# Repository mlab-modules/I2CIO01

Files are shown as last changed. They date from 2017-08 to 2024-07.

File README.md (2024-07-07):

# I2CIO01A - I2C IO Expander

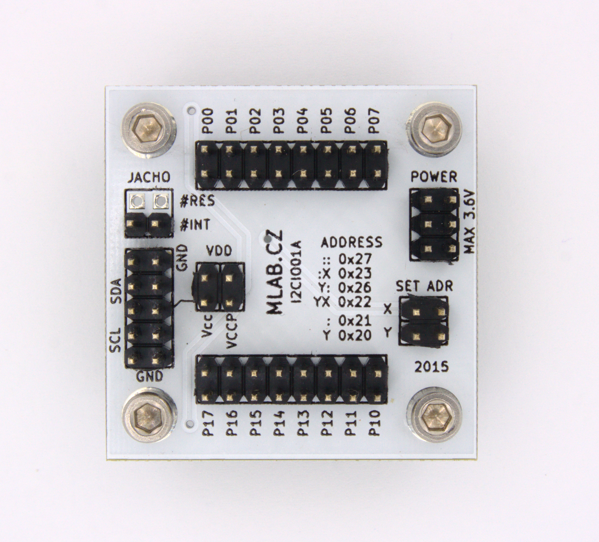
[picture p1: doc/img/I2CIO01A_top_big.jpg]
I2CIO01A


## Overview

The I2CIO01 module is a GPIO expander designed for operation in the range of 1.65 to 5.5 V. It provides general-purpose remote I/O expansion via the I²C interface. The module comprises two 8-bit Configurable, Input Ports, Output Port, and Polarity Inversion registers.

## Features

- **Operating Voltage:** 1.65 to 5.5 V
- **Interfaces:** I²C, up to 400 kHz
- **GPIO Ports:** 16-bit expansion using either TCA6416A or TCA9535 IC
- **Address Selection:**
  - TCA6416A: 2 I2C addresses, includes a reset pin
  - TCA9535: 4 I2C addresses
- **Interrupt Capabilities:** Both ICs support interrupt output
- **Package Dimensions:** 40.13 x 40.13 x 16 mm

## Technical Specifications

| Parameter | Value | Note |
|---|---|---|
| Power Supply | Max. 3.6 V | |
| ICs Used | TCA6416A or TCA9535 | |
| Interface bus | I²C | Frequency up to 400 kHz |
| Main Usage | I²C IO expander | |
| Dimensions | 40.13 x 40.13 x 16 mm | Height above the baseboard |

## Design Details

### IC Selection variants
- **TCA6416A:**
  - Populate RES, do not populate ADR X
  - Jumper to Vccp and VDD
- **TCA9535:**
  - Do not populate RES, populate ADR X
  - Jumper to Vccp and VDD

### Schematic and Layout

The module's design and layout files can be found in the `hw/sch_pcb` directory. The board is designed using KiCad.

## Bill of Materials

| Designator | Type | Package | Quantity |
|---|---|---|---|
| J3 | JUMP_3X2 | Pin_Header_Straight_2x03 | 1 |
| R1, R2, R3, ... | 10k | SMD-0805 | 13 |
| U1 | TCA6416A | TSSOP-28 | 1 |
| J8, J5 | CONN1_2 | Pin_Header_Straight_1x02 | 2 |
| P1, P2, P3, P4  | MountingHole_3mm | | 4 |
| J1 | JUMP_2X2 | Pin_Header_Straight_2x02 | 1 |
| J2 | JUMP_5X2 | Pin_Header_Straight_2x05 | 1 |
| J6, J7 | JUMP_8X2 | Pin_Header_Straight_2x08 | 2 |
| J4, J9 | CONN_2 | Pin_Header_Straight_1x02 | 2 |
| C1 | 10uF | SMD-0805 | 1 |
| C2 | 100nF | SMD-0805 | 1 |
| D1 | BZV55C-3,6V | Diode-MiniMELF_Standard | 1 |

## Assembly and Testing

1. **Assembly:** Follow the provided schematic and BOM for assembling the module.
2. **Initial Inspection:** Perform a visual inspection to ensure no shorts on the power supply.
3. **Testing:** No additional setup is required beyond the initial inspection.

For more detailed information on each component, please refer to their respective datasheets:

- [TCA6416A Datasheet](https://www.ti.com/product/TCA6416A)
- [TCA9535 Datasheet](https://www.ti.com/product/TCA9535)

## Contributing

Contributions are welcome! Please fork this repository and submit a pull request with your changes.

## Contact

For more information, visit the [MLAB website](http://www.mlab.cz) or contact us at support@mlab.cz.

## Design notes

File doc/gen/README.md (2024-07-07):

# PCB

Board size: 40.13x40.13 mm (1.58x1.58 inches)

- This is the size of the rectangle that contains the board
- Thickness: 1.6 mm (63 mils)
- Material: FR4
- Finish: HAL
- Layers: 2
- Copper thickness: 35 µm

Solder mask: TOP / BOTTOM

- Color: Green

Silk screen: TOP / BOTTOM

- Color: White

# Important sizes

Clearance: 0.2 mm (8 mils)

Track width: 0.38 mm (15 mils)

- By design rules: 0.25 mm (10 mils)

Drill: 0.75 mm (30 mils)

- Vias: 0.75 mm (30 mils) [Design: 0.6 mm (24 mils)]
- Pads: 1.0 mm (39 mils)
- The above values are real drill sizes, they add 0.1 mm (4 mils) to plated holes (PTH)

Via: 0.89/0.64 mm (35/25 mils)

- By design rules: 0.89/0.51 mm (35/20 mils)
- Micro via: yes [0.51/0.13 mm (20/5 mils)]
- Buried/blind via: yes
- Total: 3 (thru: 3 buried/blind: 0 micro: 0)

Outer Annular Ring: 0.07 mm (3 mils)

- By design rules: 0.33 mm (13 mils)

Eurocircuits class: 10A
- Using min drill 0.75 mm for an OAR of 0.07 mm

# General stats

Components count: (SMD/THT)

- Top: 0/13 (THT)
- Bottom: 25/0 (SMD)

Defined tracks:

- 0.38 mm (15 mils)
- 0.51 mm (20 mils)

Used tracks:

- 0.38 mm (15 mils) (161) defined: yes
- 0.51 mm (20 mils) (52) defined: yes

Defined vias:

Used vias:

- 0.89/0.64 mm (35/25 mils) (Count: 3, Aspect: 1.8 A) defined: no

Holes (excluding vias):

- 0.9 mm (35 mils) (60)
- 3.0 mm (118 mils) (4)

Oval holes:

Drill tools (including vias and computing adjusts and rounding):

- 0.75 mm (30 mils) (3)
- 1.0 mm (39 mils) (60)
- 3.1 mm (122 mils) (4)

Solder paste stats:

Using a paste with 87.75 % alloy, that has an specific gravity for the alloy of 7.4 g/cm³
and 1.0 g/cm³ for the flux. This paste has an specific gravity of  4.15 g/cm³.

The stencil thickness is  0.12 mm.

| Side | Pads with paste | Area [mm²] | Paste [g] |
|---|---|---|---|
| Total  | 72 | 76.34 | 0.38 |

Note: this is just an approximation to the theoretical value. Margins of the solder mask and waste aren't computed.

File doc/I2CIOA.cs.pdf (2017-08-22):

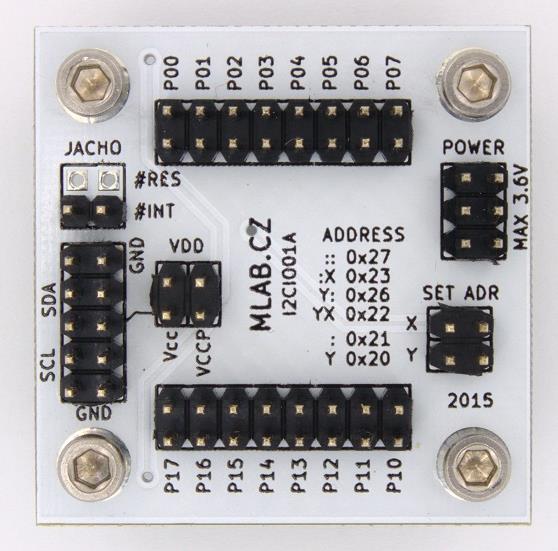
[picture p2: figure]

I2CIO01A / 2016-02-26 / jacho/ http://www.mlab.cz | 1 / 4
I2CIO01A | MLAB

# 16-Bit I2C expander

Jan Chroust

### Modul může být osazen integrovaným obvodem TCA6416A nebo

TCA9535. Oba obvody umožňují vytvořit 16-Bitový I2C expander. Obvod TCA9535 nabízí možnost volby mezi čtveřicí I2C adres,

### kdežto TCA6416A nabízí pouze dvě. TCA6416A má navíc resetový

pin. Oba dva obvody umožňují interrupt.

# 1. Technické parametry

Parametr | Hodnota | Poznámka
Napájení | Max. 3,6 V
Integrovaný obvod | TCA6416A nebo TCA9535
Rozhraní | I2C | Frekvence až 400kHz
Hlavní využití | I2C expander
Rozměry | 40.13 x 40.13 x 16 mm | Výška nad základní deskou

I2CIO01A | MLAB

# 2. Popis konstrukce

## 2.1. Úvod

TCA6416A – osadit RES a neosadit ADR X + jump na Vccp a VDD

TCA9535 - neosadit RES a osadit ADR X + jump na Vccp a VDD

I2CIO01A | MLAB

## 2.2. Zapojení

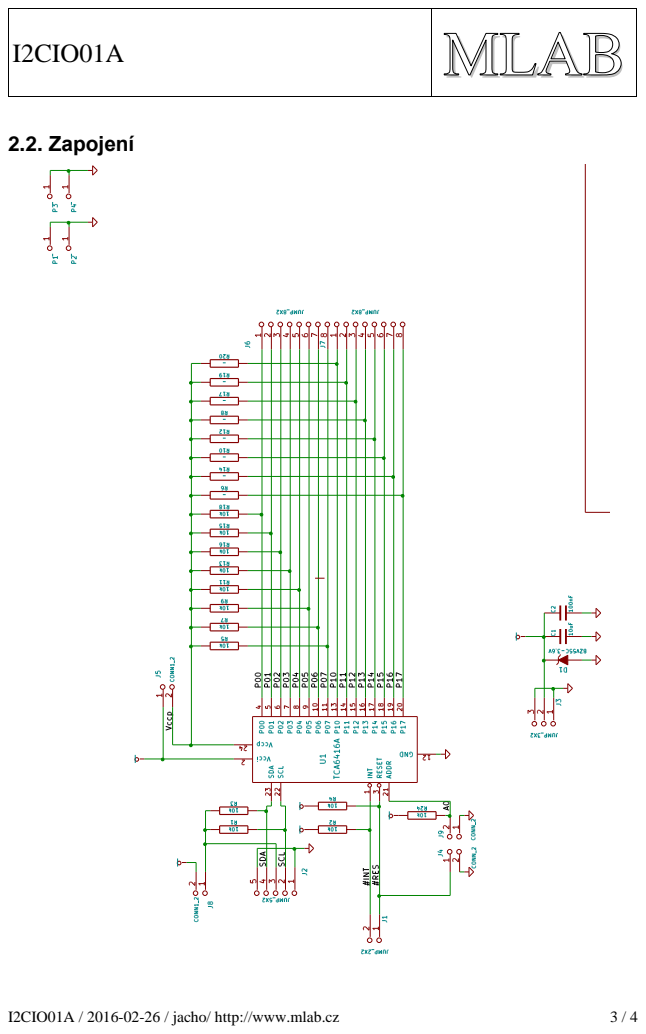
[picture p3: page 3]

I2CIO01A | MLAB

# 3. Osazení a oživení

## 3.1. Osazení

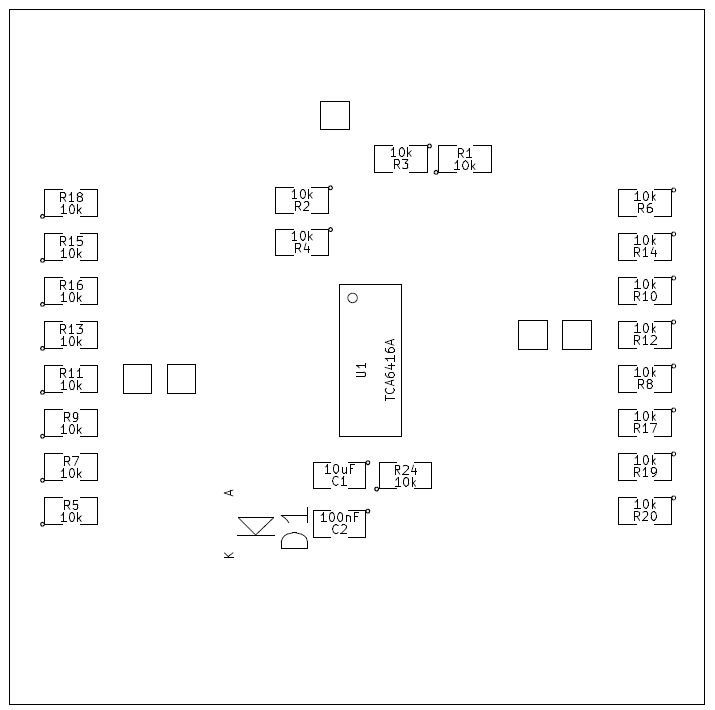
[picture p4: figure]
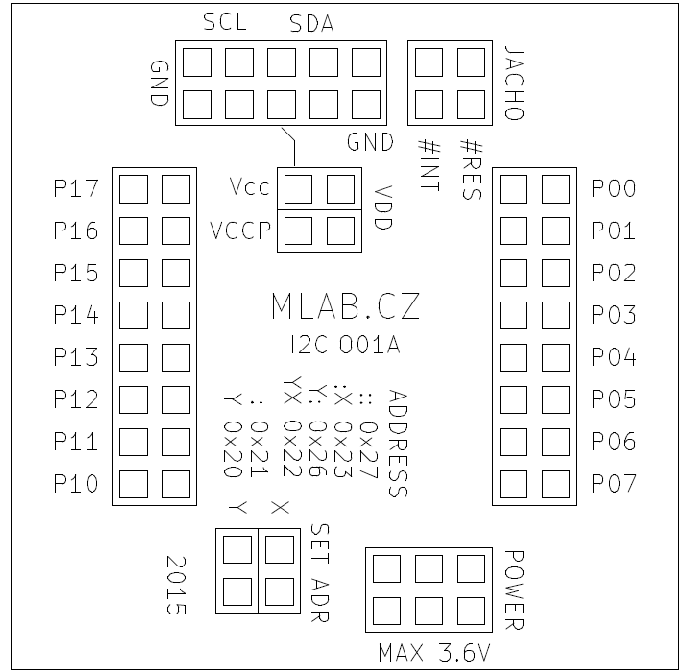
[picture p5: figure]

Označení | Typ | Pouzdro | Počet
J3 | JUMP_3X2 | Pin_Header_Straight_2x03 | 1
R1,R2,R3,R4,R5,R7,R 9,R11,R13,R15,R16,R1 8,R24 | 10k | SMD-0805 | 13
R6,R8,R10,R12,R14,R 17,R19,R20 | - | SMD-0805 | 8
U1 | TCA6416A | TSSOP-28 | 1
J8,J5 | CONN1_2 | Pin_Header_Straight_1x02 | 2
P1,P2,P3,P4 | _ | MountingHole_3mm | 4
J1 | JUMP_2X2 | Pin_Header_Straight_2x02 | 1
J2 | JUMP_5X2 | Pin_Header_Straight_2x05 | 1
J6,J7 | JUMP_8X2 | Pin_Header_Straight_2x08 | 2
J4,J9 | CONN_2 | Pin_Header_Straight_1x02 | 2
C1 | 10uF | SMD-0805 | 1
C2 | 100nF | SMD-0805 | 1
D1 | BZV55C-3,6V | Diode-MiniMELF_Standard | 1

## 3.2. Oživení

Po osazení modulu je dobré provést vizuální kontrolu, případně proměřit, zda na napájení není zkrat. Další oživení není potřeba.

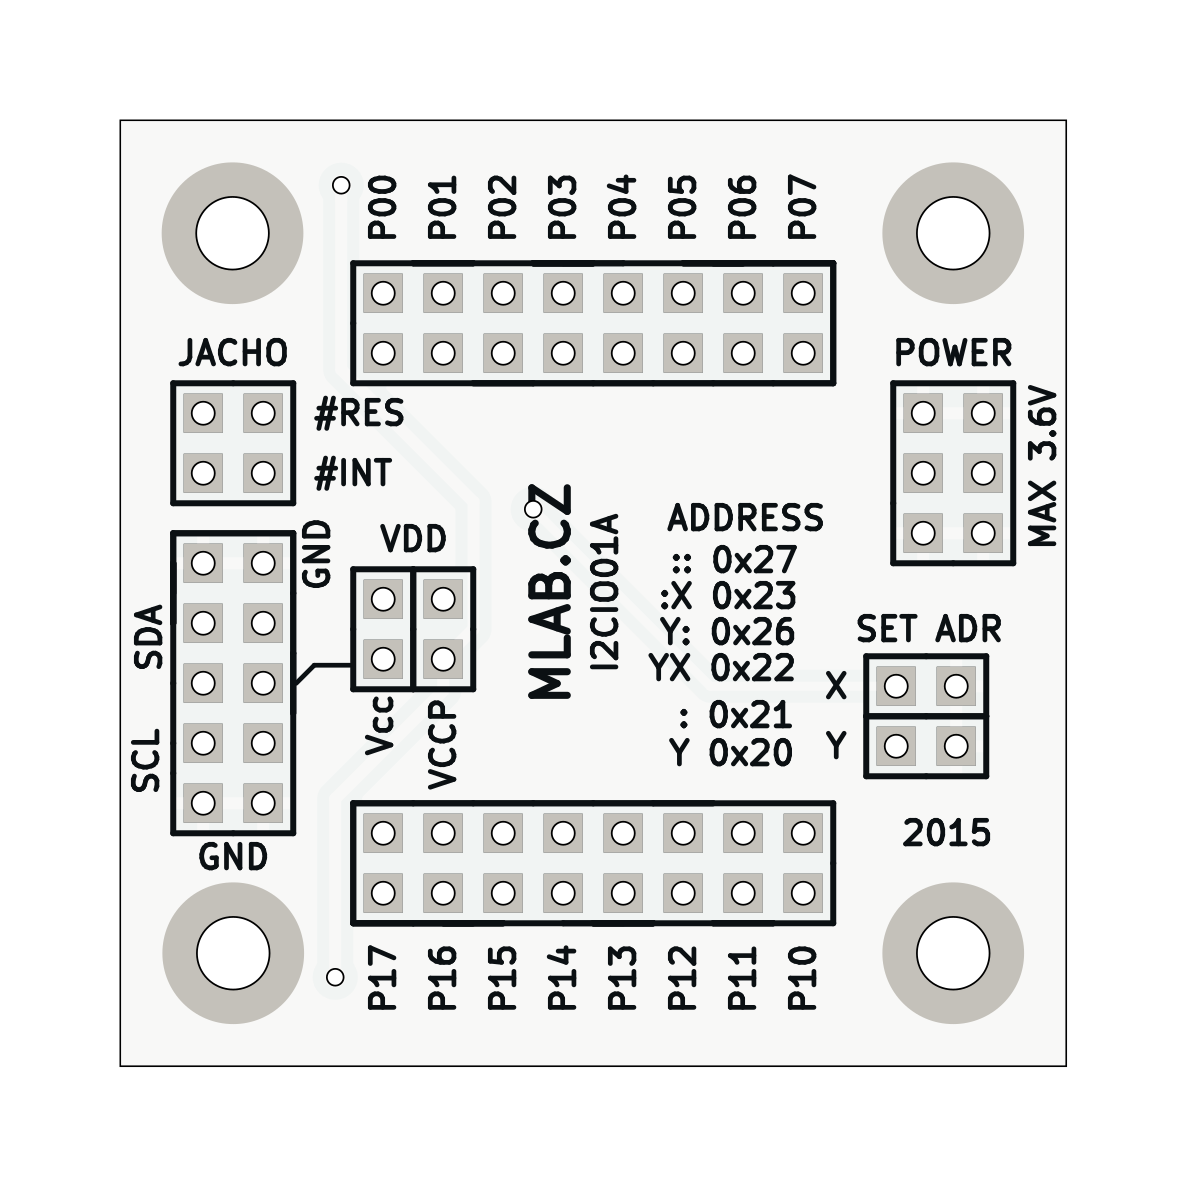
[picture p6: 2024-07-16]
doc/gen/img/I2CIO01-top.png

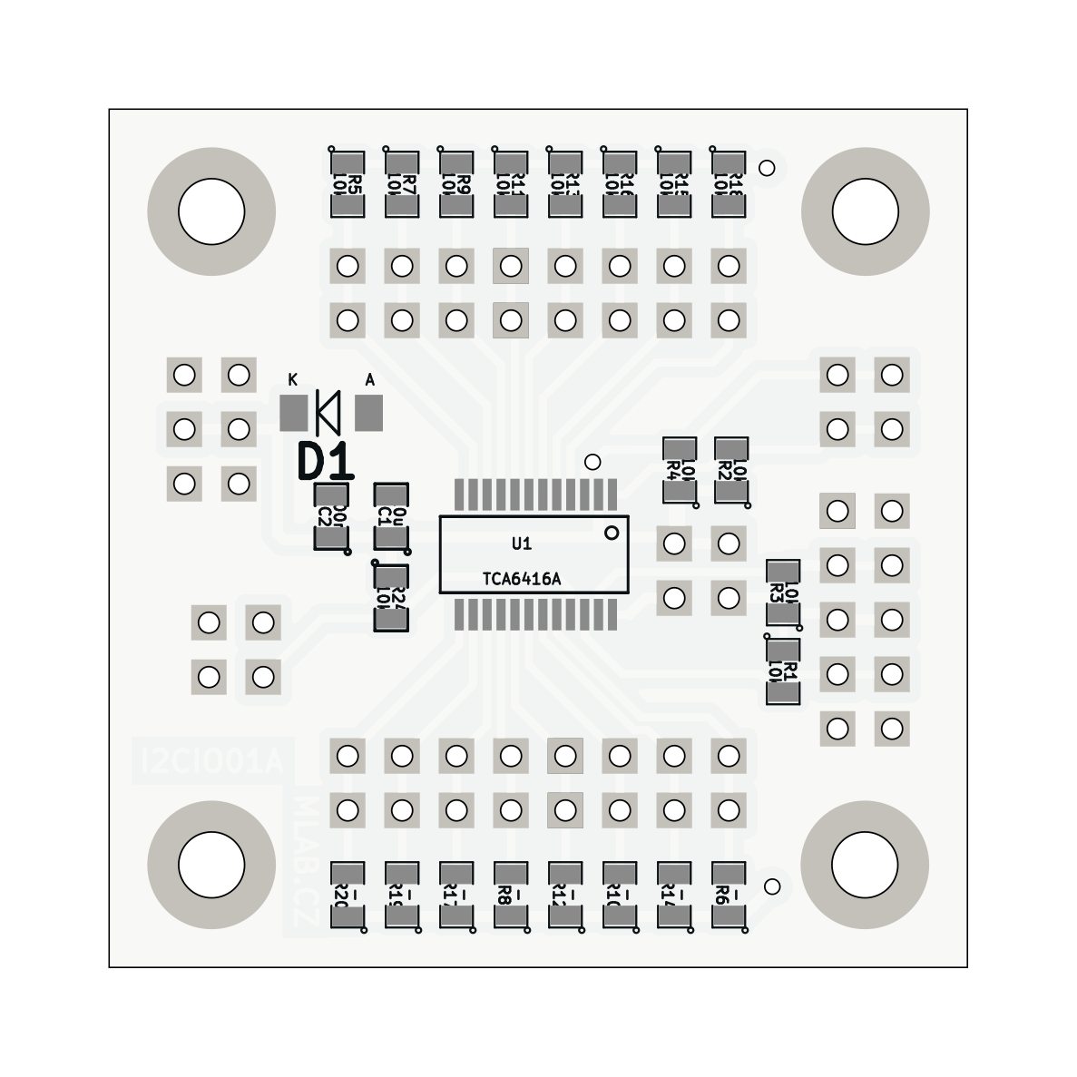
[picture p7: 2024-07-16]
doc/gen/img/I2CIO01-bottom.png

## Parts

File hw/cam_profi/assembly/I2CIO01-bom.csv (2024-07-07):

Component | Description | Part | References | Value | Footprint | Quantity Per PCB | Datasheet
1 |  | C | C2 | 100nF | SMD-0805 | 1
2 |  | C | C1 | 10uF | SMD-0805 | 1
3 |  | ZENER | D1 | BZV55C-3,6V | Diode-MiniMELF_Standard | 1
4 |  | CONN1_2 | J5J8 | CONN1_2 | Pin_Header_Straight_1x02 | 2
5 |  | CONN_2 | J4J9 | CONN_2 | Pin_Header_Straight_1x02 | 2
6 |  | JUMP_2X2 | J1 | JUMP_2X2 | Pin_Header_Straight_2x02 | 1
7 |  | JUMP_3X2 | J3 | JUMP_3X2 | Pin_Header_Straight_2x03 | 1
8 |  | JUMP_5X2 | J2 | JUMP_5X2 | Pin_Header_Straight_2x05 | 1
9 |  | JUMP_8X2 | J6J7 | JUMP_8X2 | Pin_Header_Straight_2x08 | 2
10 |  | R | R1R2R3R4R5R7R9R11R13R15R16R18R24 | 10k | SMD-0805 | 13
11 |  | R | R6R8R10R12R14R17R19R20 | - | SMD-0805 | 8
12 |  | TCA6416A | U1 | TCA6416A | TSSOP-28 | 1

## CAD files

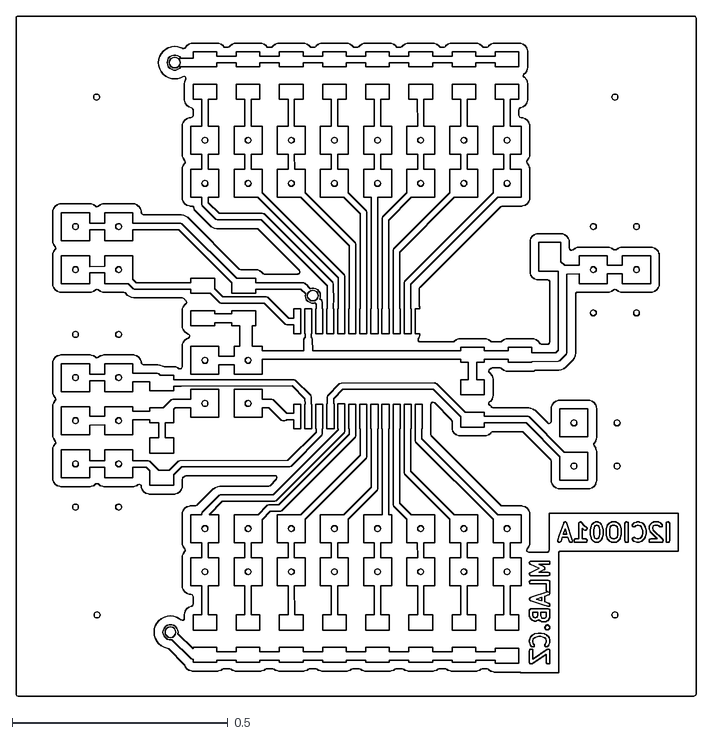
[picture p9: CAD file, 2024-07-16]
doc/gen/dxf/I2CIO01-B_Cu.dxf
1.58 x 1.58

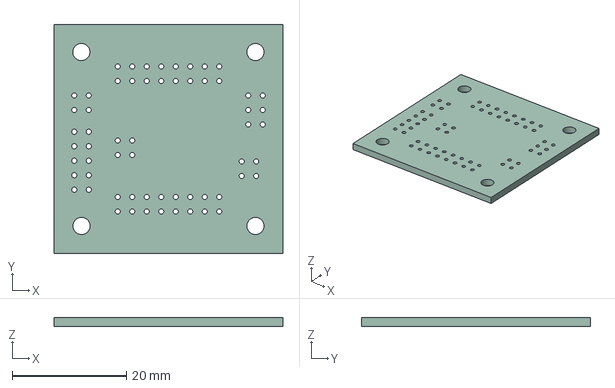
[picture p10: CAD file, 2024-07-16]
doc/gen/I2CIO01.step
40.1 x 40.1 x 1.60 mm

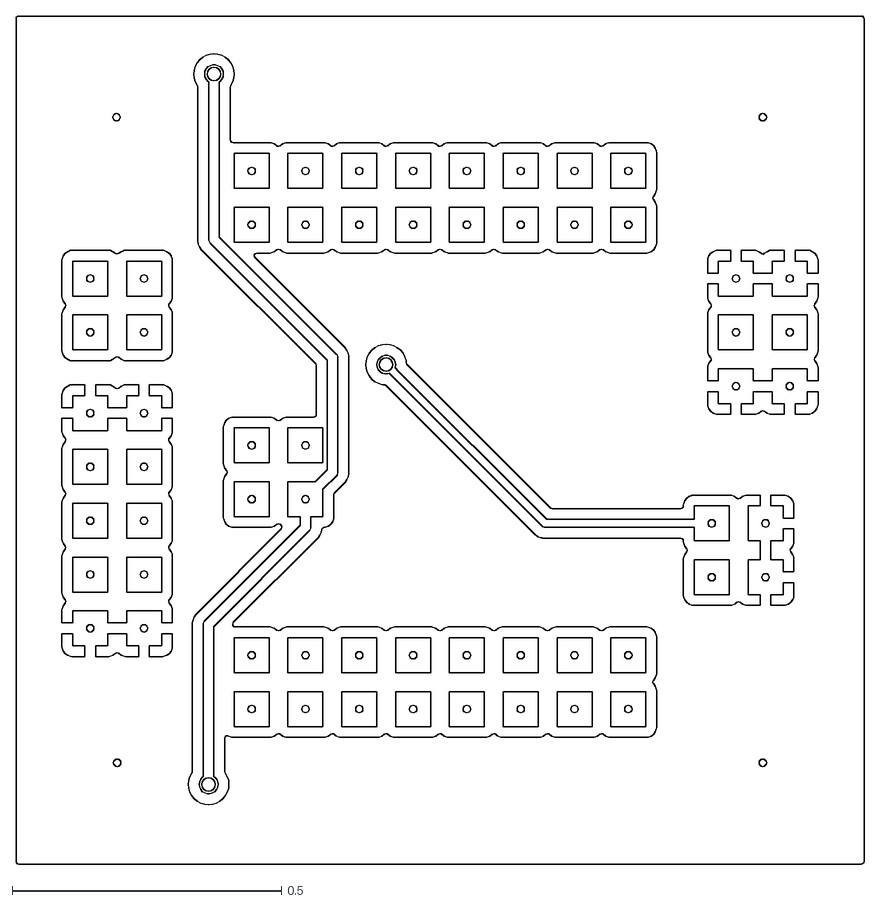
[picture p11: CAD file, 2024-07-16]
doc/gen/dxf/I2CIO01-F_Cu.dxf
1.58 x 1.58

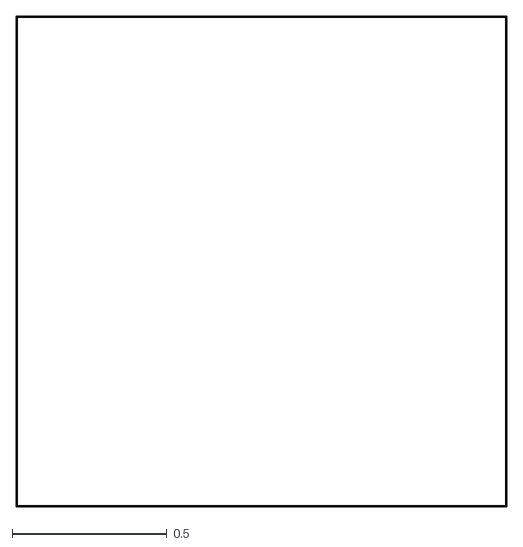
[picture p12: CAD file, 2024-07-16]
doc/gen/dxf/I2CIO01-Edge_Cuts.dxf
1.58 x 1.58

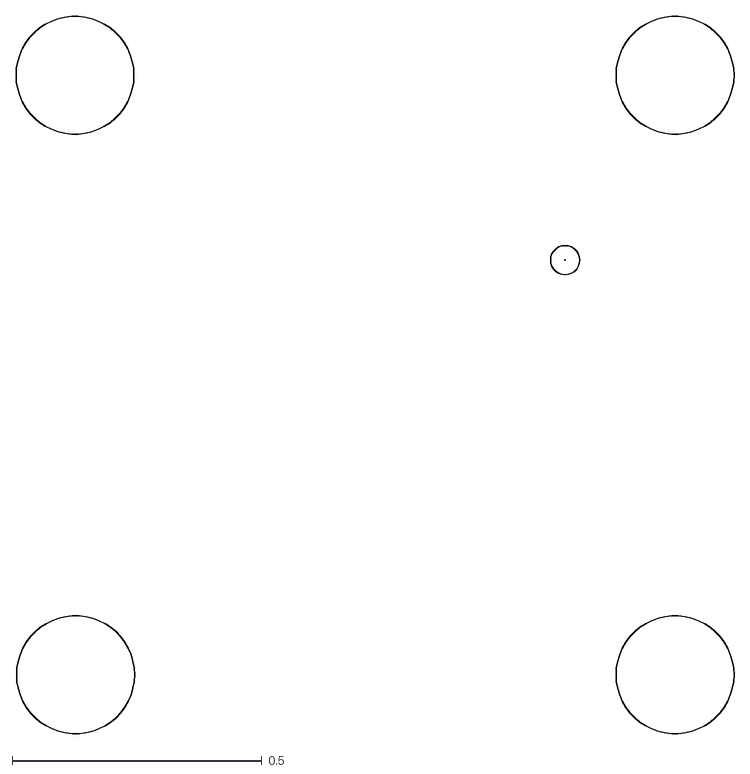
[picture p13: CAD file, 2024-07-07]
doc/gen/dxf/I2CIO01-B_Adhesive.dxf
1.44 x 1.44

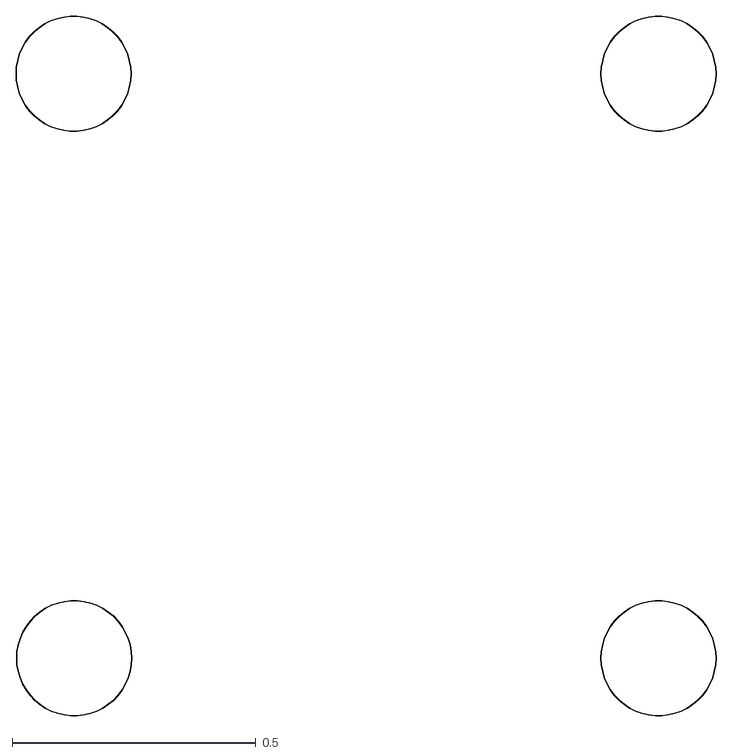
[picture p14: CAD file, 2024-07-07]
doc/gen/dxf/I2CIO01-F_Adhesive.dxf
1.44 x 1.44

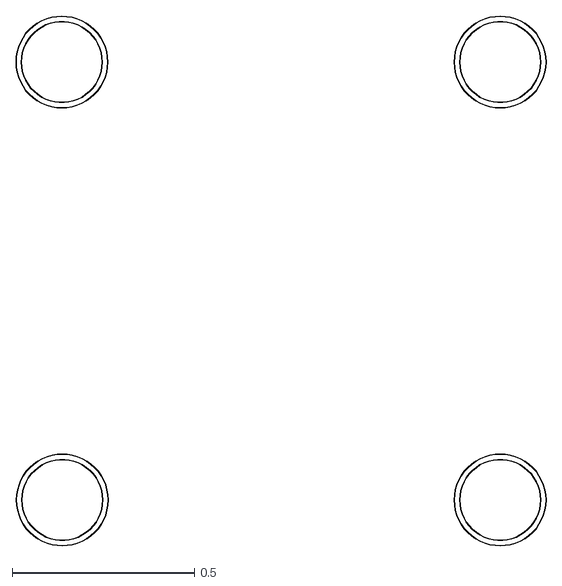
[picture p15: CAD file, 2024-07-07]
doc/gen/dxf/I2CIO01-User_Comments.dxf
1.45 x 1.45

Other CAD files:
doc/gen/dxf/I2CIO01-F_Fab.dxf
doc/gen/dxf/I2CIO01-User_Drawings.dxf
doc/gen/dxf/I2CIO01-User_Eco2.dxf
doc/gen/dxf/I2CIO01-B_Courtyard.dxf
doc/gen/dxf/I2CIO01-Margin.dxf
doc/gen/dxf/I2CIO01-F_Courtyard.dxf
doc/gen/dxf/I2CIO01-B_Fab.dxf
doc/gen/dxf/I2CIO01-User_Eco1.dxf
doc/gen/dxf/I2CIO01-B_Mask.dxf
doc/gen/dxf/I2CIO01-B_Paste.dxf
doc/gen/dxf/I2CIO01-B_Silkscreen.dxf
doc/gen/dxf/I2CIO01-F_Mask.dxf
doc/gen/dxf/I2CIO01-F_Paste.dxf
doc/gen/dxf/I2CIO01-F_Silkscreen.dxf

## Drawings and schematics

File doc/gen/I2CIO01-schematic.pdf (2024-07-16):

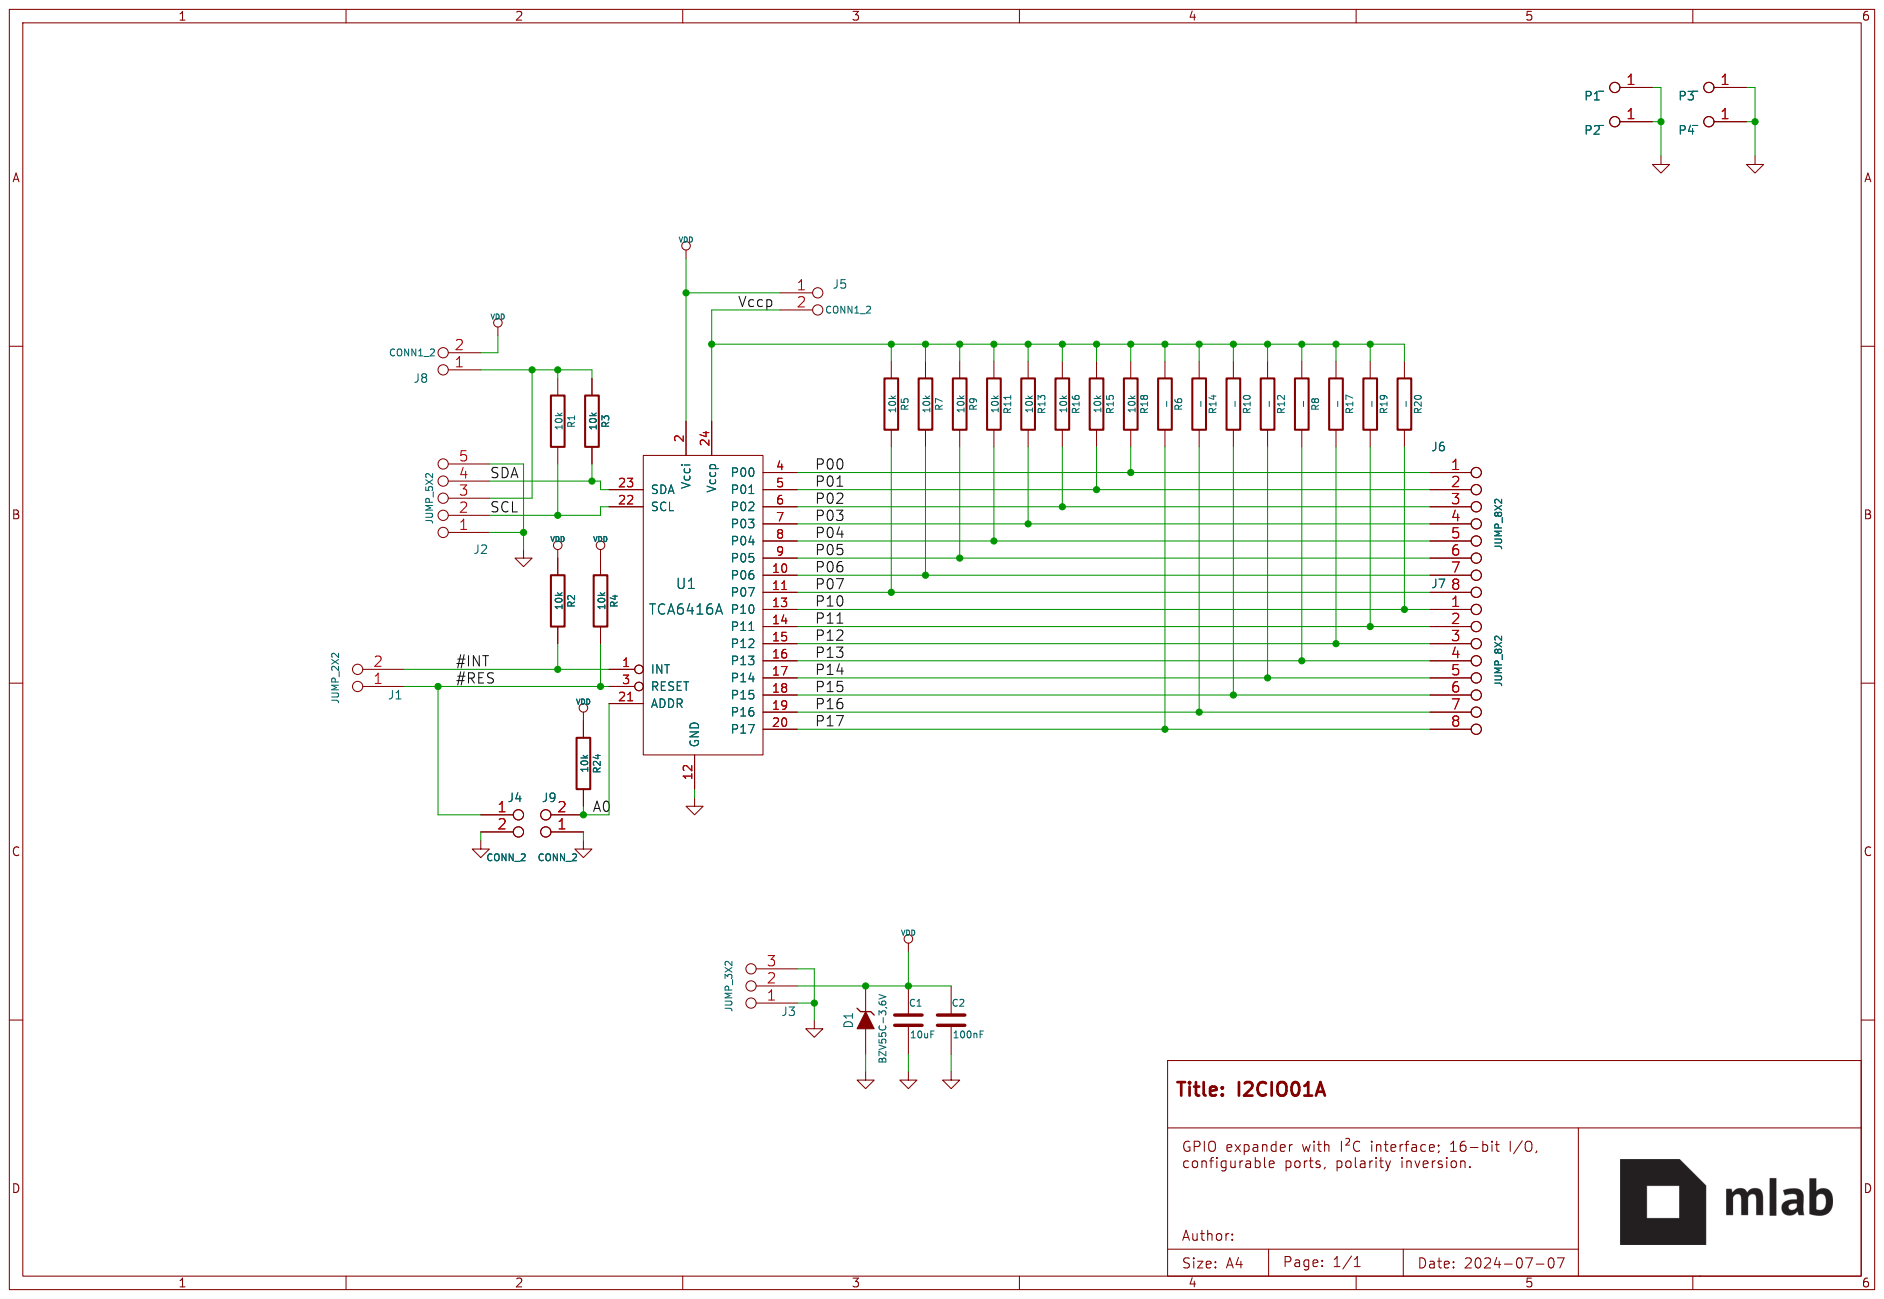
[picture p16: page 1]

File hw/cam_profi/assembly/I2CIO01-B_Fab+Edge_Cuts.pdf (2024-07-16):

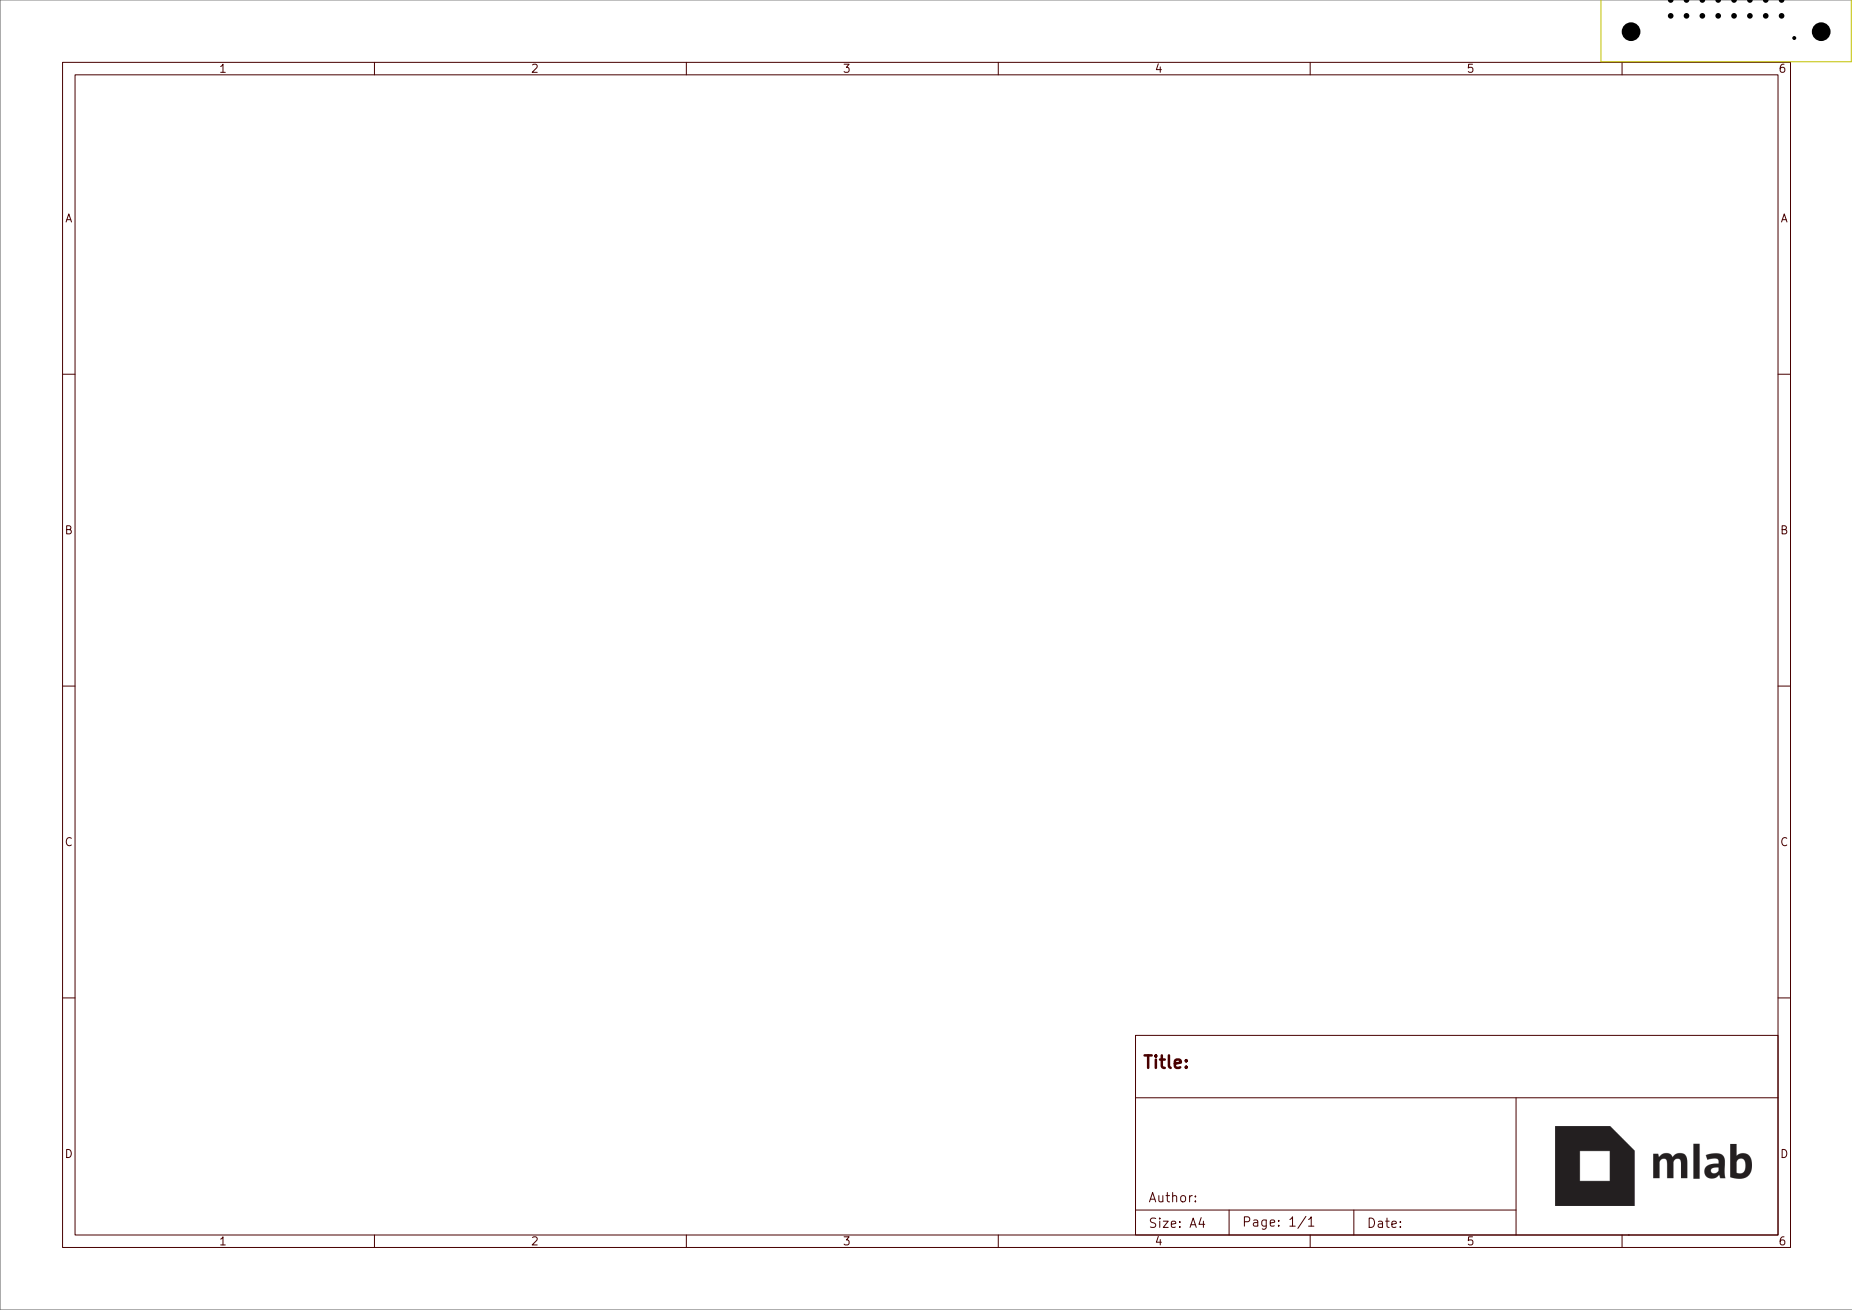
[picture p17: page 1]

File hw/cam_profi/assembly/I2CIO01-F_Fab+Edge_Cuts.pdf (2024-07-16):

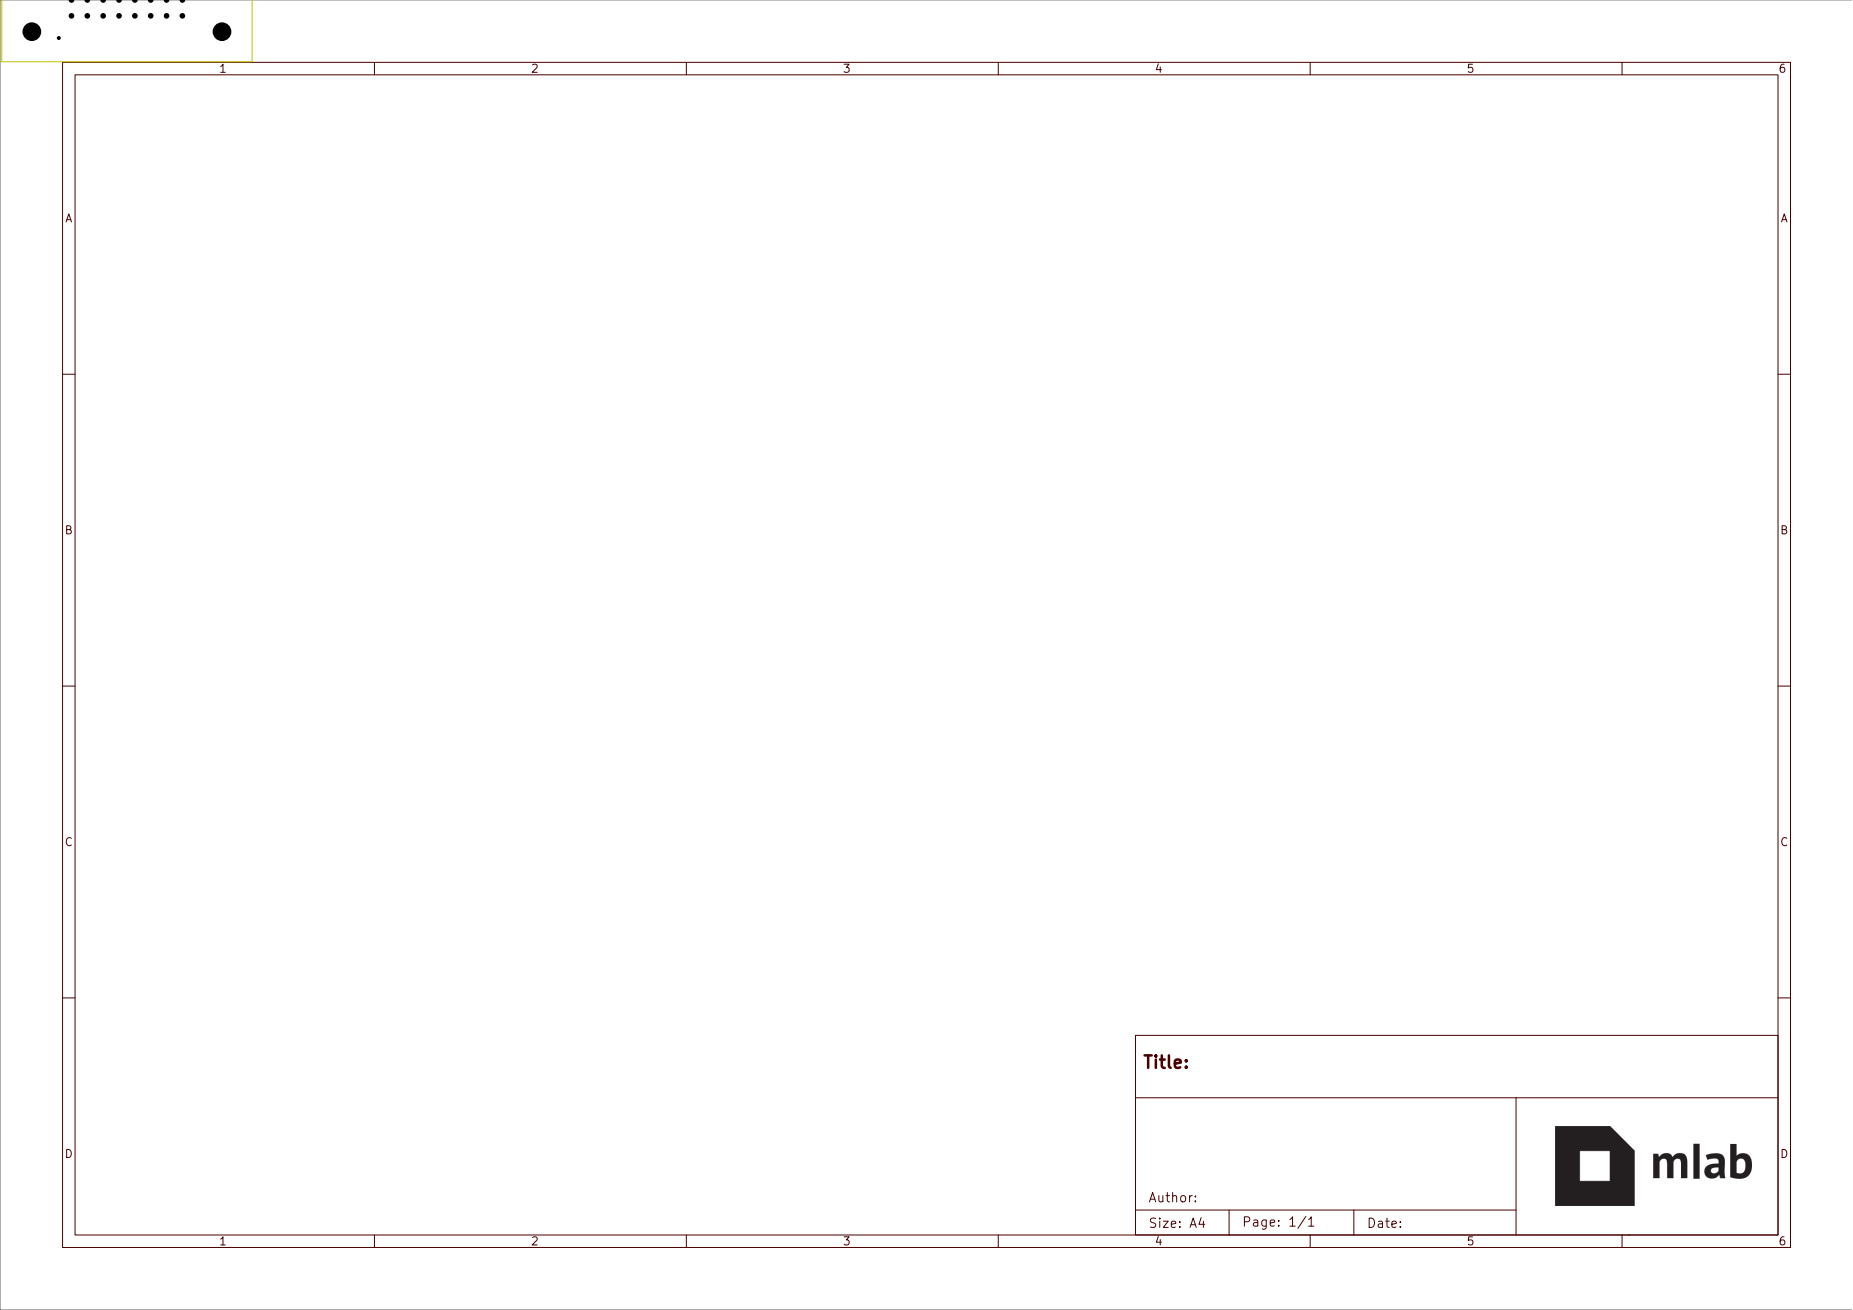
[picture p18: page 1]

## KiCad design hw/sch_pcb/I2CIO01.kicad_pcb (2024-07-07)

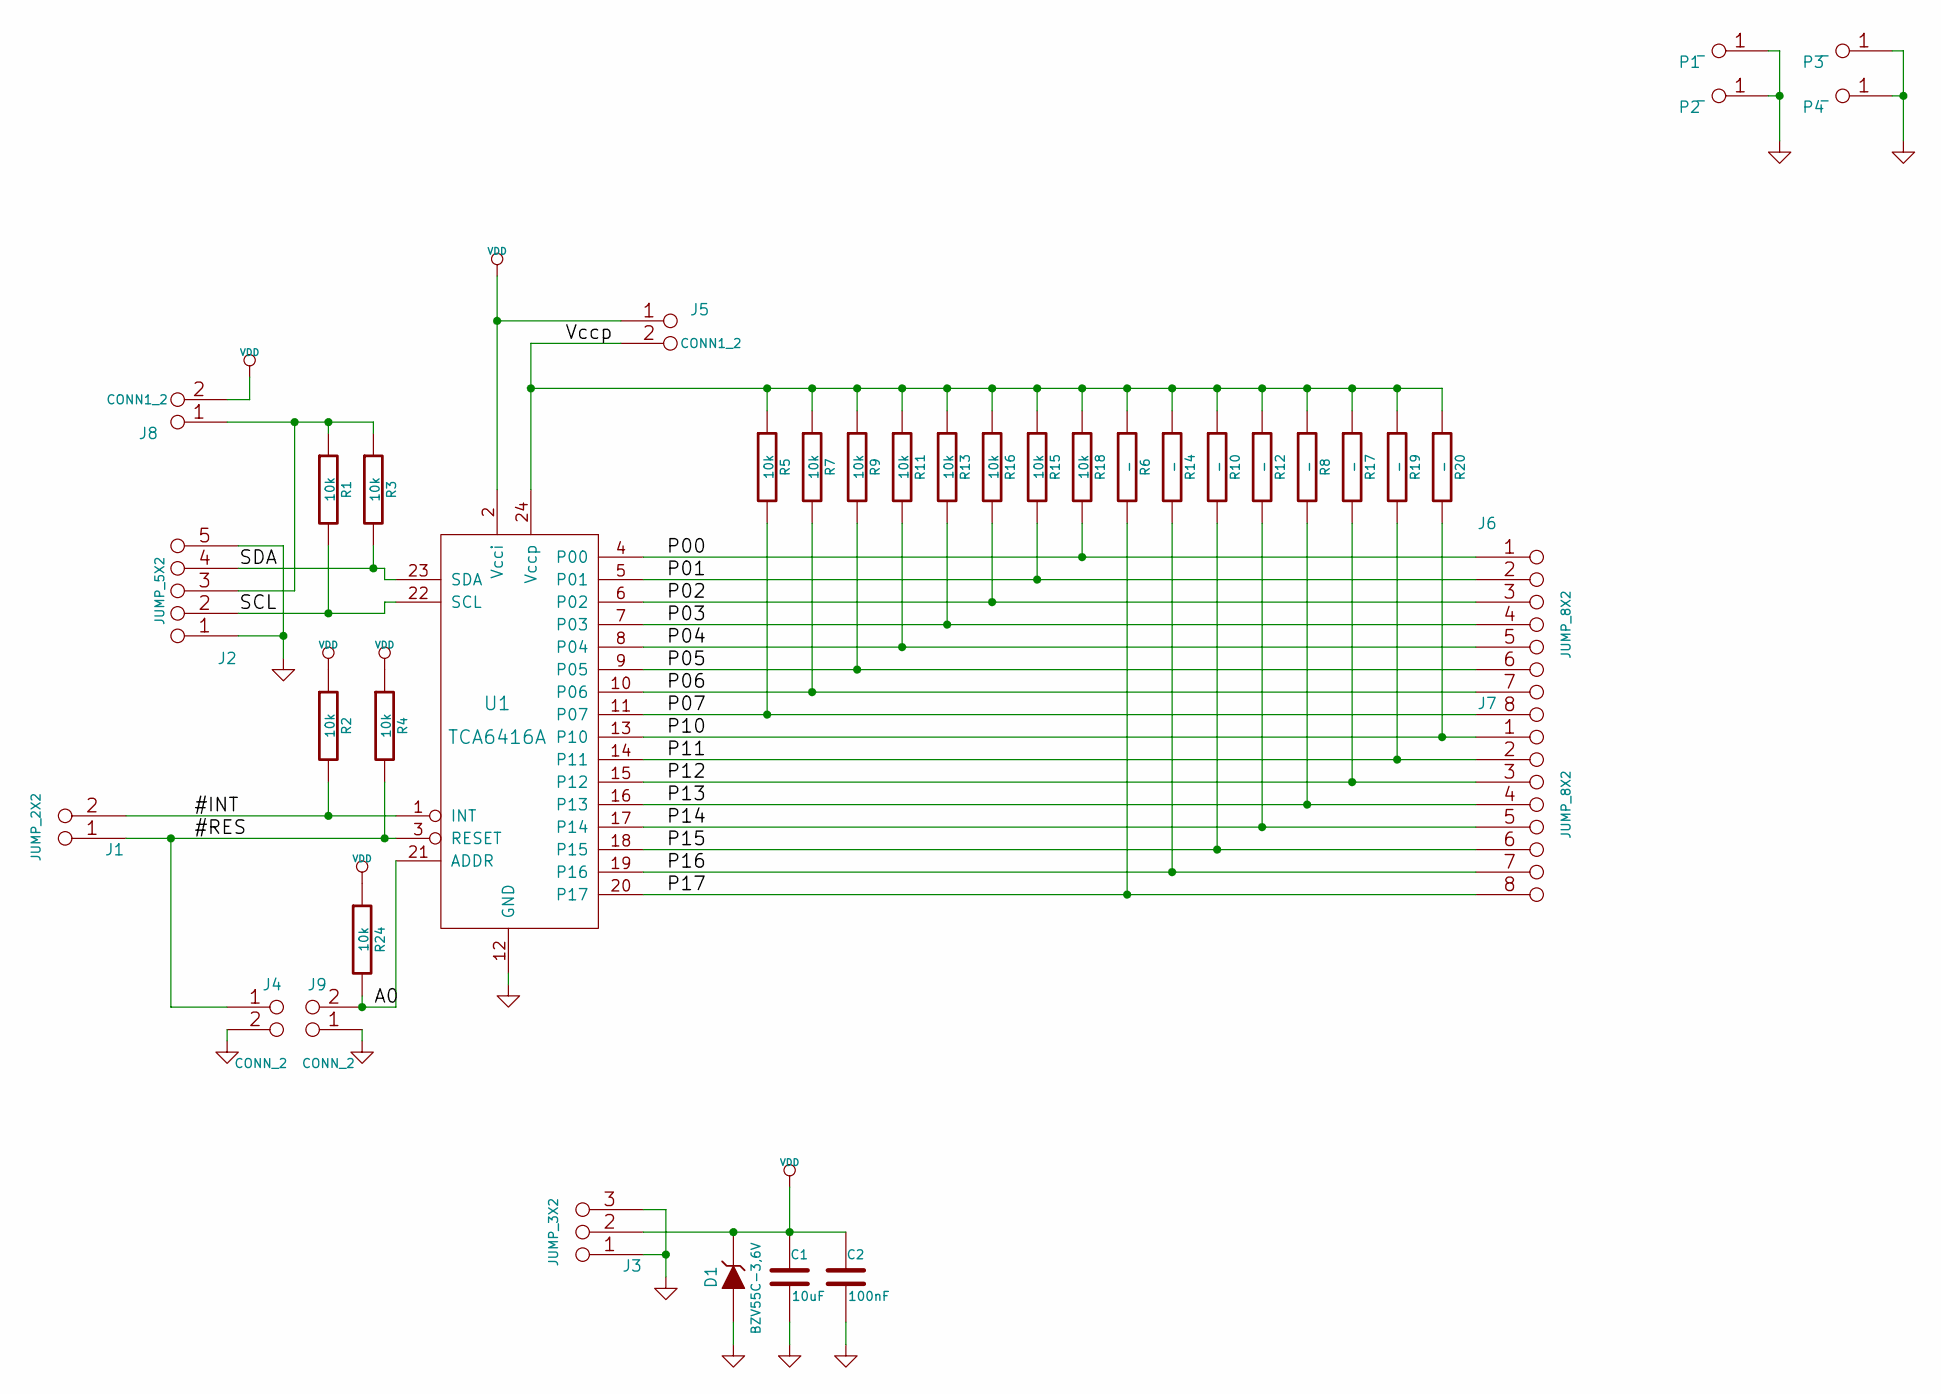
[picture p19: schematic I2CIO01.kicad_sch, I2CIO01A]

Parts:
C1: 10uF; SMD-0805
C2: 100nF; SMD-0805
D1: BZV55C-3,6V; Diode-MiniMELF_Standard
J1: JUMP_2X2; Pin_Header_Straight_2x02
J2: JUMP_5X2; Pin_Header_Straight_2x05
J3: JUMP_3X2; Pin_Header_Straight_2x03
J4, J9: CONN_2; Pin_Header_Straight_1x02
J5, J8: CONN1_2; Pin_Header_Straight_1x02
J6, J7: JUMP_8X2; Pin_Header_Straight_2x08
P1, P2, P3, P4: _; MountingHole_3mm
R1, R2, R3, R4, R5, R7, R9, R11, R13, R15, R16, R18, R24: 10k; SMD-0805
R6, R8, R10, R12, R14, R17, R19, R20: -; SMD-0805
U1: TCA6416A; TSSOP-28

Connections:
/#INT: J1.2 (1), J1.3, R2.2, U1.1 (INT)
/#RES: J1.1, J1.4, J4.1, R4.2, U1.3 (RESET)
/A0: J9.2 (PM), R24.2, U1.21 (ADDR)
/P00: J6.1, J6.16, R18.2, U1.4 (P00)
/P01: J6.2, J6.15, R15.2, U1.5 (P01)
/P02: J6.3, J6.14, R16.2, U1.6 (P02)
/P03: J6.4, J6.13, R13.2, U1.7 (P03)
/P04: J6.5, J6.12, R11.2, U1.8 (P04)
/P05: J6.6, J6.11, R9.2, U1.9 (P05)
/P06: J6.7, J6.10, R7.2, U1.10 (P06)
/P07: J6.8, J6.9, R5.2, U1.11 (P07)
/P10: J7.1, J7.16, R20.2, U1.13 (P10)
/P11: J7.2, J7.15, R19.2, U1.14 (P11)
/P12: J7.3, J7.14, R17.2, U1.15 (P12)
/P13: J7.4, J7.13, R8.2, U1.16 (P13)
/P14: J7.5, J7.12, R12.2, U1.17 (P14)
/P15: J7.6, J7.11, R10.2, U1.18 (P15)
/P16: J7.7, J7.10, R14.2, U1.19 (P16)
/P17: J7.8, J7.9, R6.2, U1.20 (P17)
/SCL: J2.2, J2.9, R1.2, U1.22 (SCL)
/SDA: J2.4, J2.7, R3.2, U1.23 (SDA)
/Vccp: J5.2 (PM), R5.1, R6.1, R7.1, R8.1, R9.1, R10.1, R11.1, R12.1, R13.1, R14.1, R15.1, R16.1, R17.1, R18.1, R19.1, R20.1, U1.24 (Vccp)
GND: C1.2, C2.2, D1.1 (A), J2.1, J2.5, J2.6, J2.10, J3.1, J3.3, J3.4, J3.6, J4.2 (PM), J9.1, P1.1, P2.1, P3.1, P4.1, U1.12 (GND)
unnamed: J2.3, J2.8, J8.1, R1.1, R3.1
VDD: C1.1, C2.1, D1.2 (K), J3.2 (1), J3.5, J5.1, J8.2 (PM), R2.1, R4.1, R24.1, U1.2 (Vcci)

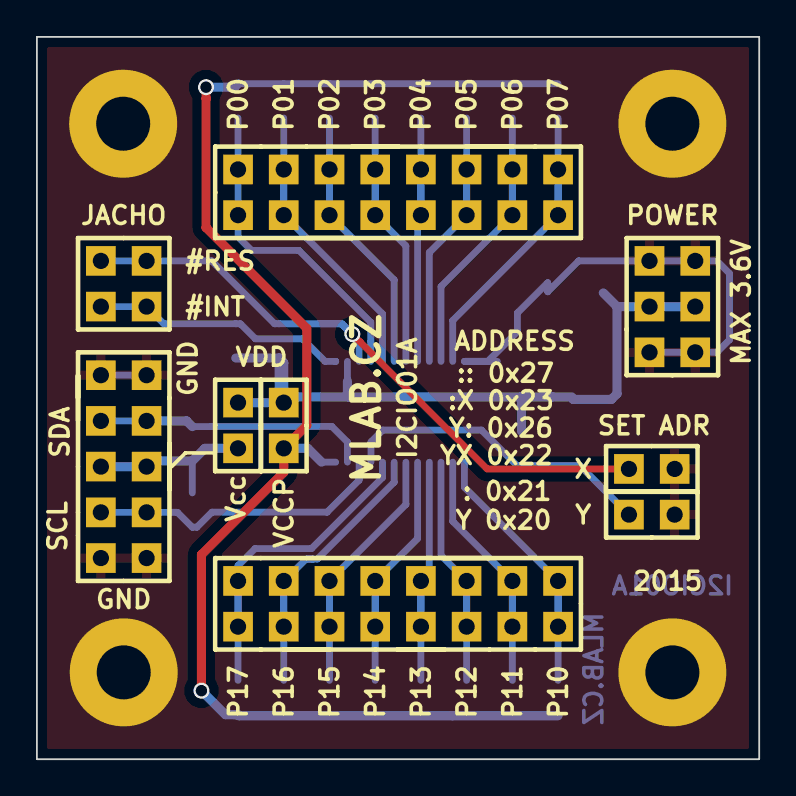
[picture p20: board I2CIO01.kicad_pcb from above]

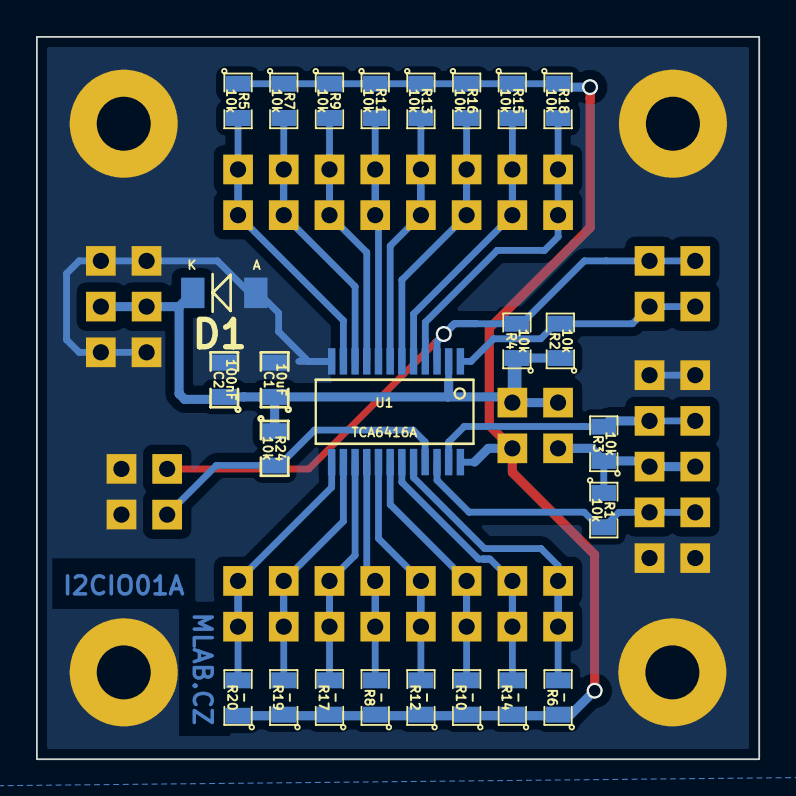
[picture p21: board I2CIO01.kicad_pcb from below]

Board: 2 copper layers, 40.1 x 40.1 mm, 38 parts (25 on the bottom side), 25 nets.

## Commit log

2017-08-22 rename category folders
    [I2CIO01A-B_Cu.gbr, I2CIO01A-B_Mask.gbr, I2CIO01A-B_SilkS.gbr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]
2017-08-22 rename files and module folders
    [I2CIO01A-B_Cu.gbr, I2CIO01A-B_Mask.gbr, I2CIO01A-B_SilkS.gbr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]
2017-08-22 create hw folder
    [I2CIO01A-B_Cu.gbr, I2CIO01A-B_Mask.gbr, I2CIO01A-B_SilkS.gbr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]
2017-08-22 change filepaths
    [I2CIO01A.kicad_pcb, I2CIO01A.sch]
2017-11-06 [MLABweb] 2017-11-06 09:59:10 I2CIO01A
2022-04-06 Update actions products
    [I2CIO01A-B_Cu.gbr, I2CIO01A-B_Mask.gbr, I2CIO01A-B_SilkS.gbr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]
2023-07-05 automated commit; rename source files to new naming convence
    [I2CIO01.kicad_pcb]
2024-07-07 Update documentation and upgrade to KiCADv7.
    [I2CIO01.kicad_sch, I2CIO01A.sch]
2024-07-07 Update PCB to KiCADv7.
    [I2CIO01.kicad_pcb]
